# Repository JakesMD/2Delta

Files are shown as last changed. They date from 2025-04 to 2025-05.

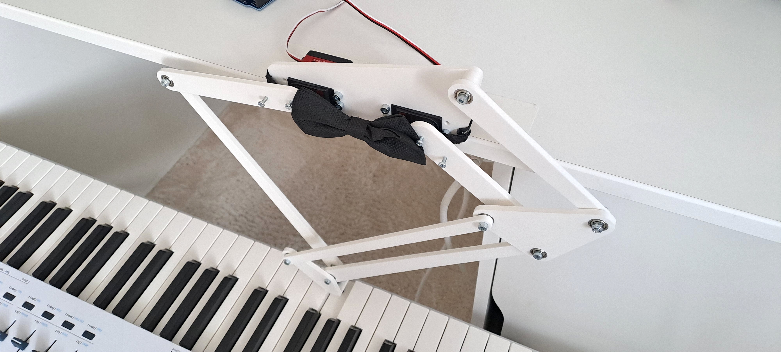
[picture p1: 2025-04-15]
images/2delta.jpg

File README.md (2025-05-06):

2Delta

# 2Delta
**An open-source 2-axis delta robot.**

The great thing about delta, is it only uses 2 small servo motors, but it has a quite a large workspace.

## Usage

### Configure [config.h](src/config.h)
Carefully adjust the values based on your robot's physical dimensions and the specifications in your servo motor datasheets.

**Incorrect configuration will lead to self-destruction!**

### Basic control

```c++
#include <delta.h>
#include <Servo.h>

Delta delta;

void setup() {
    Serial.begin(9600);

    // CAREFUL: This will move the servos to the home position
    //          with no control over speed!!
    delta.begin();
}

void loop() {
    delta.setSpeed(50); // Speed in mm/s

    // Move to (x, y) in mm.
    //
    // This will return `false` if
    // - the position is out of bounds
    // - getting there would cause a collision.
    delta.moveTo(100, 200); 
    delta.setSpeed(200);
    delta.moveTo(-50, 300);
}
```

`moveTo` is blocking, so let me know if you need a non-blocking version.

### Uploading the code
**Turn off the power to the servos before uploading!**

Uploading can interfere with the PWM signals and cause the servos to go crazy until the robot is destroyed.

In future versions, I'll add an upload button, which will detach the servos before uploading.

## Assembly

### Hardware
- [x] 1x Arduino
- [x] 1x 5V 3A power supply
- [x] 2x Standard servos with metal servo horns ([Amazon](https://www.amazon.de/dp/B0BBZFDJJ6))
- [x] 9x 624Z bearings
- [x] 15x M4 locknuts
- [x] 4x 16mm M4 screws
- [x] 8x 20mm M4 screws
- [x] 1x 25mm M4 screw
- [x] 1x 30mm M4 screw
- [x] 1x 35mm M4 screw
- [x] 4x 10mm M3 screws

## Future improvements

Currently, the inverse kinematics uses `acos`, which can be inaccurate for `acos(1-)` and `acos(-1+)`. It would be better to use `atan2` instead.

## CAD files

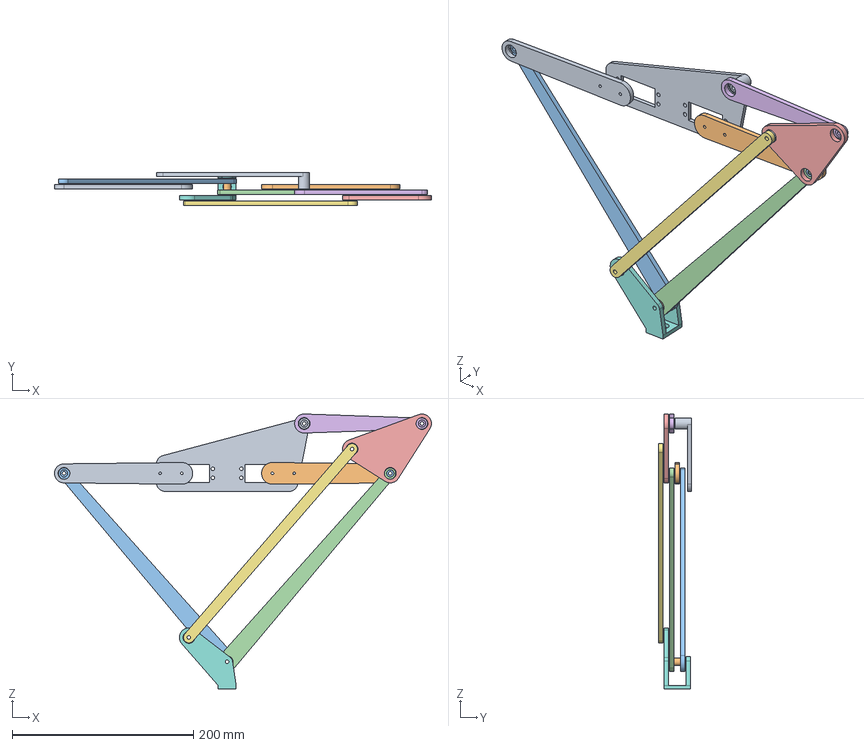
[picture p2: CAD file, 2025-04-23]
2delta.step
416.0 x 36.0 x 303.4 mm
Left upper arm
Right upper arm
Left lower arm
Right lower arm
Helper triangle
Upper helper arm
Lower helper arm
Flange
Servo mount
Flange washer
Helper triangle washer

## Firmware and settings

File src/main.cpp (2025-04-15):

#include <Arduino.h>
#include <Servo.h>
#include <math.h>

#include "delta.h"

Delta delta;

uint16_t pressY = 277;
uint16_t releaseY = 250;

unsigned long millisPlayed;

byte bpm = 45;
uint16_t msPerBeat = 60000 / bpm;

void playNote(int note, float noteValue) {
    delta.moveTo(note, releaseY);

    while (millis() < millisPlayed);

    delta.moveTo(note, pressY);
    int delayTime = msPerBeat * noteValue * 0.25;
    if (delayTime > 0) delay(delayTime);
    delta.moveTo(note, releaseY);

    millisPlayed += (msPerBeat * (noteValue * 100)) / 100;
}

void leftHand() {
    int b = 25 * 4;
    int c = 25 * 3;
    int d = 25 * 2;
    int e = 25;
    int f = 0;
    int g = -25;
    int a = -25 * 2;
    int b2 = -25 * 3;
    int c2 = -25 * 4;

    millisPlayed = millis();
    delta.moveTo(e, releaseY);
    while (millis() - millisPlayed < 2000);

    millisPlayed = millis();

    playNote(e, 1);
    playNote(c, 1);

    playNote(g, 2);
    playNote(b, 2);

    playNote(c, 2);
    playNote(e, 1);
    playNote(c2, 1);

    playNote(d, 1);
    playNote(b2, 1);
    playNote(c2, 1);
    playNote(c, 1);

    playNote(g, 2);
    playNote(e, 1);
    playNote(c, 1);

    playNote(g, 2);
    playNote(b, 2);

    playNote(c, 2);
    playNote(a, 1);
    playNote(c2, 1);

    playNote(f, 1);
    playNote(c2, 1);
    playNote(g, 1);
    playNote(b2, 1);

    playNote(c2, 2);
}

void rightHand() {
    int g = 25 * 3;
    int c = 0;
    int d = -25;
    int e = -25 * 2;
    int f = -25 * 3;
    int g2 = -25 * 4;

    millisPlayed = millis();
    delta.moveTo(c, releaseY);
    while (millis() - millisPlayed < 2000);

    millisPlayed = millis();

    playNote(c, 1);
    playNote(e, 1);

    playNote(d, 1);
    playNote(g, 1);
    playNote(d, 0.5);
    playNote(e, 0.5);
    playNote(f, 0.5);
    playNote(d, 0.5);

    playNote(e, 1);
    playNote(c, 1);
    playNote(g2, 2);

    playNote(f, 2);
    playNote(e, 0.5);
    playNote(d, 0.5);
    playNote(e, 0.5);
    playNote(f, 0.5);

    playNote(e, 1);
    playNote(d, 1);
    playNote(c, 1);
    playNote(e, 1);

    playNote(d, 1);
    playNote(g, 1);
    playNote(d, 0.5);
    playNote(e, 0.5);
    playNote(f, 0.5);
    playNote(d, 0.5);

    playNote(e, 1);
    playNote(c, 1);
    playNote(f, 2);

    playNote(e, 2);
    playNote(d, 0.5);
    playNote(c, 0.5);
    playNote(d, 0.5);
    playNote(e, 0.5);

    playNote(c, 2);
}

void setup() {
    Serial.begin(9600);

    delta.begin();
    delta.setSpeed(200);

    delay(4000);
}

void loop() {
    rightHand();
    delay(1000);
}

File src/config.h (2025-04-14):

#ifndef CONFIG_H
#define CONFIG_H

#include <math.h>

// The pins of the servos.
#define LEFT_SERVO_PIN 9
#define RIGHT_SERVO_PIN 8

// The distance between the servo axes in mm.
#define SHOULDER_SPACING 100.0

// The length of the upper and lower arms in mm.
#define UPPER_ARM_LENGTH 130.0
#define LOWER_ARM_LENGTH 275.0

// The maximum servo angles in deg.
// 0 deg. is parallel to the x - axis, - is upwards, + is downwards.
#define MIN_SHOULDER_ANGLE -10.0
#define MAX_SHOULDER_ANGLE 90.0

// The maximum angle between the upper and lower arms in degrees.
#define MAX_ELBOW_ANGLE 170.0

// The offset of the servo angles in degrees.
// - is upwards, + is downwards.
#define LEFT_SERVO_ANGLE_OFFSET 0.0
#define RIGHT_SERVO_ANGLE_OFFSET 5.0

// The range of the servo angles in degrees.
#define SERVO_ANGLE_RANGE 270.0

// The minimum and maximum pulse widths in microseconds.
#define SERVO_MIN_PULSE_WIDTH 500
#define SERVO_MAX_PULSE_WIDTH 2500

// The size of the interpolation steps in mm.
#define INTERPOLATION_STEP_SIZE 2.0

// The default speed in mm/s.
#define DEFAULT_SPEED 100

#endif

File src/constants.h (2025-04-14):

#ifndef CONSTANTS_H
#define CONSTANTS_H

#include <math.h>

#define MIN_SHOULDER_ANGLE_RAD (MIN_SHOULDER_ANGLE * PI / 180.0)
#define MAX_SHOULDER_ANGLE_RAD (MAX_SHOULDER_ANGLE * PI / 180.0)
#define MAX_ELBOW_ANGLE_RAD (MAX_ELBOW_ANGLE * PI / 180.0)
#define LEFT_SERVO_ANGLE_OFFSET_RAD (LEFT_SERVO_ANGLE_OFFSET * PI / 180.0)
#define RIGHT_SERVO_ANGLE_OFFSET_RAD (RIGHT_SERVO_ANGLE_OFFSET * PI / 180.0)
#define SERVO_ANGLE_RANGE_RAD (SERVO_ANGLE_RANGE * PI / 180.0)

#define UPPER_ARM_LENGTH_SQUARE (sq(UPPER_ARM_LENGTH))
#define LOWER_ARM_LENGTH_SQUARE (sq(LOWER_ARM_LENGTH))
#define HOME_Y_POS sqrt(LOWER_ARM_LENGTH_SQUARE - sq(SHOULDER_SPACING / 2 + UPPER_ARM_LENGTH))

#endif

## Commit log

2025-04-14 🎉 Initial commit
    [2delta.step]
2025-04-15 ✨ Add video
2025-04-15 🎨 Convert to landscape
2025-04-15 ✏️ Rename moveToPos to moveTo
2025-04-15 📝 Improve documentation
2025-04-22 🐛 Fix incorrect servo dimensions
    [2delta.step]
2025-04-30 📝 Add parts list to README
2025-04-30 ✏️ Fix typo
2025-05-06 📝 Add future improvements section to README
2025-05-06 ✏️ Fix typos
